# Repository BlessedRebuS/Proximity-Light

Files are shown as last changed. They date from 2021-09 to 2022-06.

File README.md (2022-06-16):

# Proximity-Light
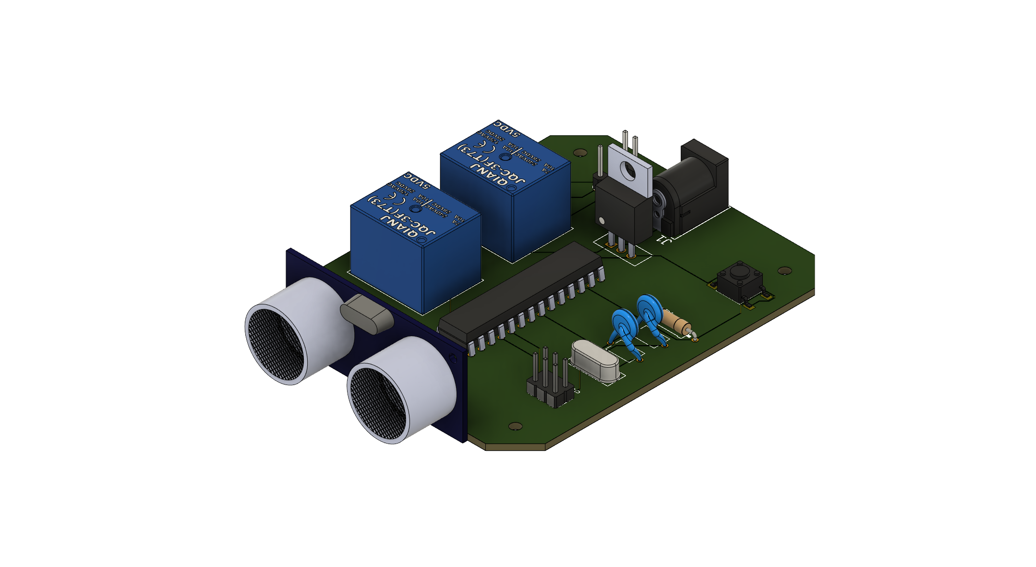
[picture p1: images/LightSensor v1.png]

Sensor Light powered by a ultrasound module (HC-SR04) built on a chip. (SMD version). 
When the proximity sensor sees an obsacle (for example your hand) the relays are toggled **(ON-OFF)** / **(OFF-OF)** and the 12v powers the pins.
The button triggers an interrupt (ATMega328P comes with D2 and D3 digital pin that can be used as interrupts, in this project only the D3 is used) that cycles 3 states:

* Relay 1 ON Relay 2 OFF
* Relay 1 ON Relay 2 ON
* Relay 1 OFF Relay 2 OFF

The project idea is to put two led strips in the pair of pins near the supply that can help you illuminate the kitchen/bathroom/other rooms. Leds can be replaced with all type of stuff you want but it hasn't to drain much current (Max around 0.1 amp), you have only to solder your device in place. Now are only supported devices without data pins, so you have to use only the **VCC** and **GND**.

[See polarity and button](https://github.com/BlessedRebuS/Proximity-Light/blob/main/images/PinButton.png)

# Board

## Electronic Board
Created with Autodesk EAGLE and Fusion360 Electronic.

To connect all pins we simply used autorouting.

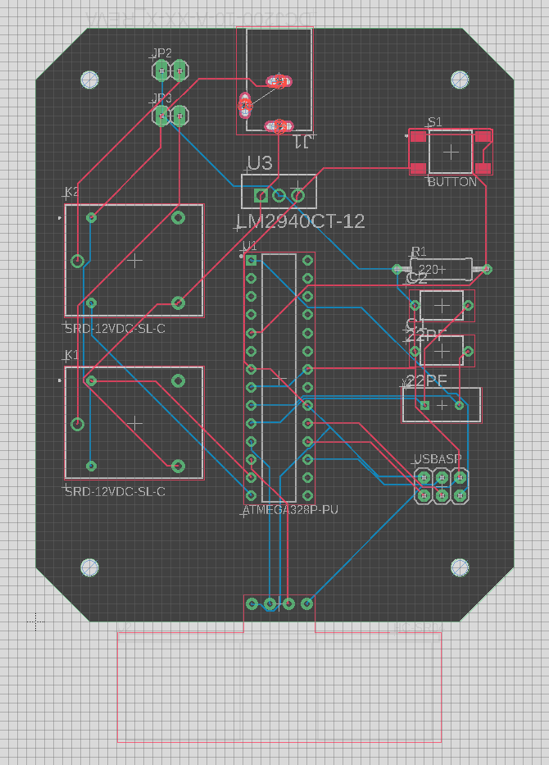
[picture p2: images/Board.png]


## Board Schematic - Libraries
You can find all the libraries *(Footprint, Symbols and 3DModels)* [Here](https://github.com/BlessedRebuS/Proximity-Light/tree/main/libraries/Footprints)

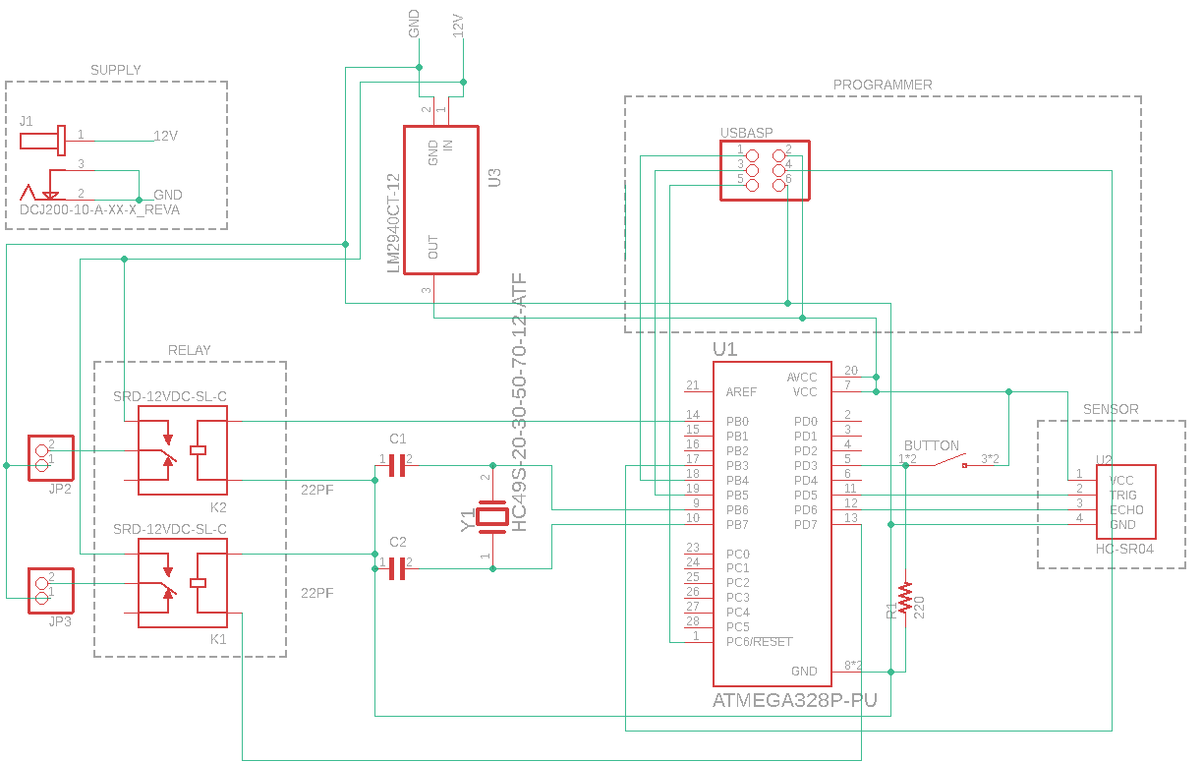
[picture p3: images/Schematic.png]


## 3D Model

Designed and rendered in Fusion360



3D Model STL
# Components

* ATMega328P  [Read more](#about-the-atmega328p)
* 22 PF Capacitors (Not polarized) 2x
* 20 MHZ Quartz Oscillator
* 220-1k OHM Resistor
* Ultrasonic Sensor (HC-SR04)
* 12 to 5V DC Mosfet
* 12V Supply Holder
* 12v Relays x2
* Button
* 2x1 pins x2
* 2x3 pins

# About the ATMega328P

ATMega328p is a very versatile processor, mounted on Arduino, that can be used also separately with a different pinout. In this case the base clock 8MHZ is replaced with the 16MHZ clock (not necessary) connected to the two grounded capacitors to generate the oscillation.

**How to program it?** I suggest to use the [USBASP programmer](www.learningaboutelectronics.com/Articles/Program-AVR-chip-using-a-USBASP-with-10-pin-cable.php) (6 or 10 PIN), but you can use an Arduino using "Arduino as ISP" programming.

## The clock
As [Here](https://doc.riot-os.org/group__boards__atmega328p.html) is explained:

> The ATmega328p has two internal oscillators clocked at 8MHz and at 128kHz that allow it to be operated without any external clock source or crystal. By default the fuses are configured to use the internal 8MHz oscillator and a clock divider resulting in a clock speed of 1MHz. By clearing the CKDIV8 fuse the clock divider can be disabled to operate the ATmega328p at 8MHz without an external clock source. This can be done like this:
> 
> `avrdude -c usbtiny -p m328p -B 32 -U lfuse:w:0xe2:m`
> 
> (Replace usbtiny with the ISP programmer you are using. The -B 32 might be needed on some ISP programmers to communicate with slow ATmega MCUs. It will not be needed anymore after the clock device has been disabled.)
This "board" is configured to use 8MHz as core clock, so that the ATmega328p runs at the highest frequency possible without external clock sources.
By setting the environment variable ATMEGA328P_CLOCK to a custom frequency in Hz (e.g. 1000000 for 1MHz), this core clock can be changed easily. Refer to the datasheet on how to configure the ATmega328p to use an external crystal, an external clock source or the clock divider.
<p align="right">


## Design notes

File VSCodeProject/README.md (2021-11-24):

# Visual Studio Code project

## Required:
* PlatformIO extension

Once you have installed PlatformIO extension you can open the project and re-compile your code.

>You can also switch Board if you desire, you just have to add your configuration to the `platformio.ini` file.
>You can find the configuration for your board [Here](https://docs.platformio.org/en/latest/boards/index.html)

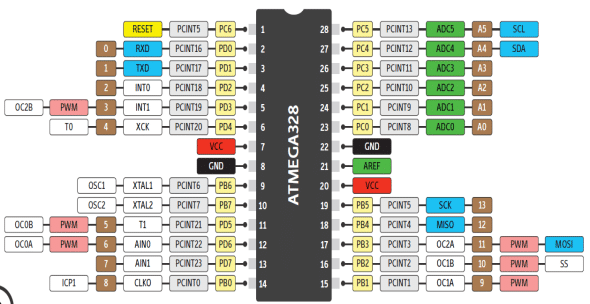
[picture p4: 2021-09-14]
Light-Sensor/img/Full pinout atmega328p.png

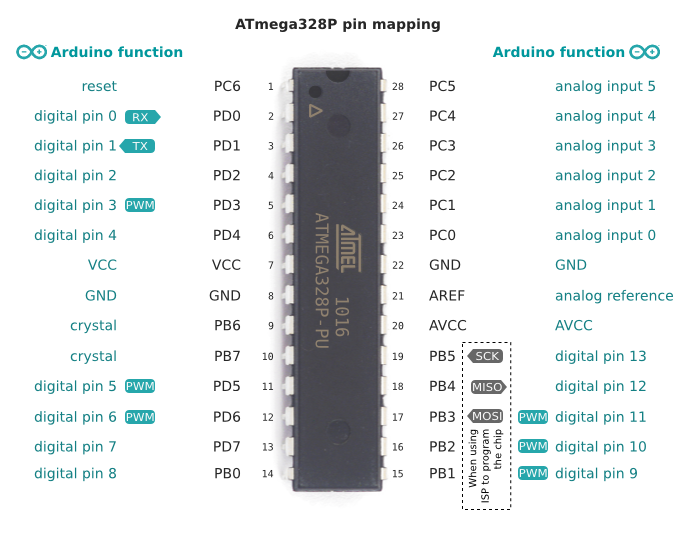
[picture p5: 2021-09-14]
Light-Sensor/img/Pinout atmega328p.png

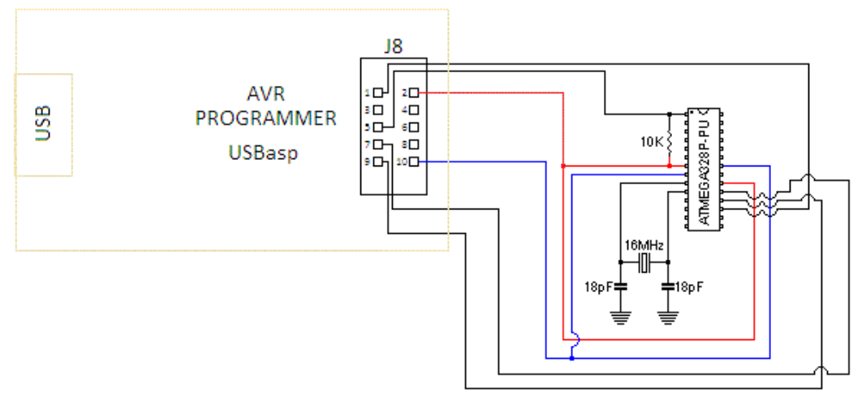
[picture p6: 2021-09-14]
Light-Sensor/img/Immagine 2021-08-31 100949.png

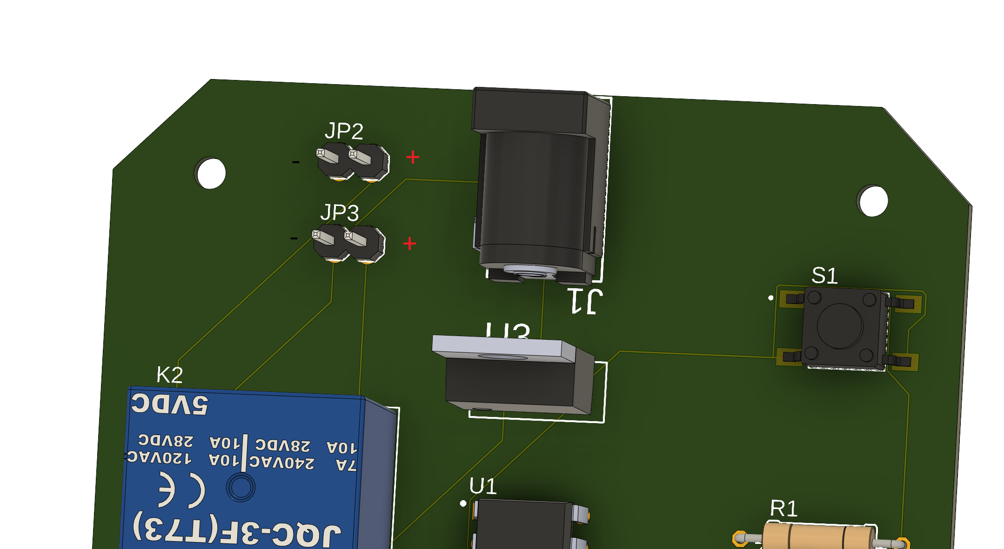
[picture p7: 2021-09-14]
images/PinButton.png

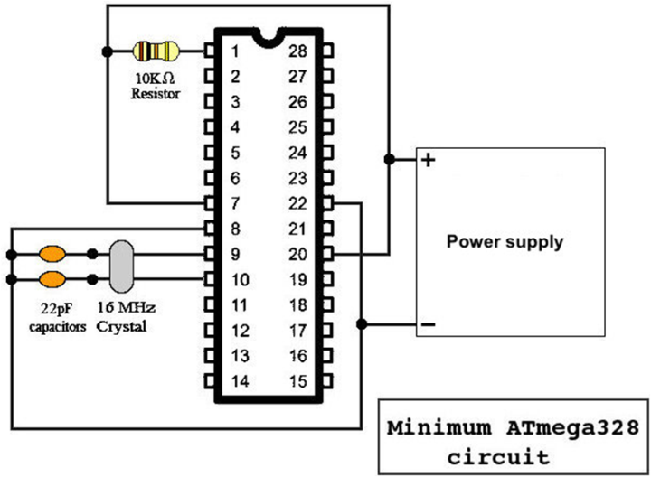
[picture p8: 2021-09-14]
Light-Sensor/img/Clock boost atmega328p.png

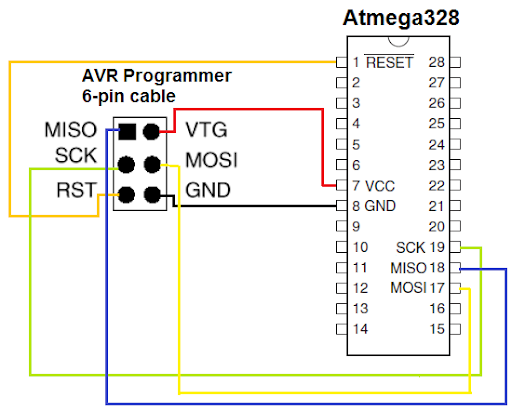
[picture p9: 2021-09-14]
Light-Sensor/img/Usbasp 6 pin atmega328p.png

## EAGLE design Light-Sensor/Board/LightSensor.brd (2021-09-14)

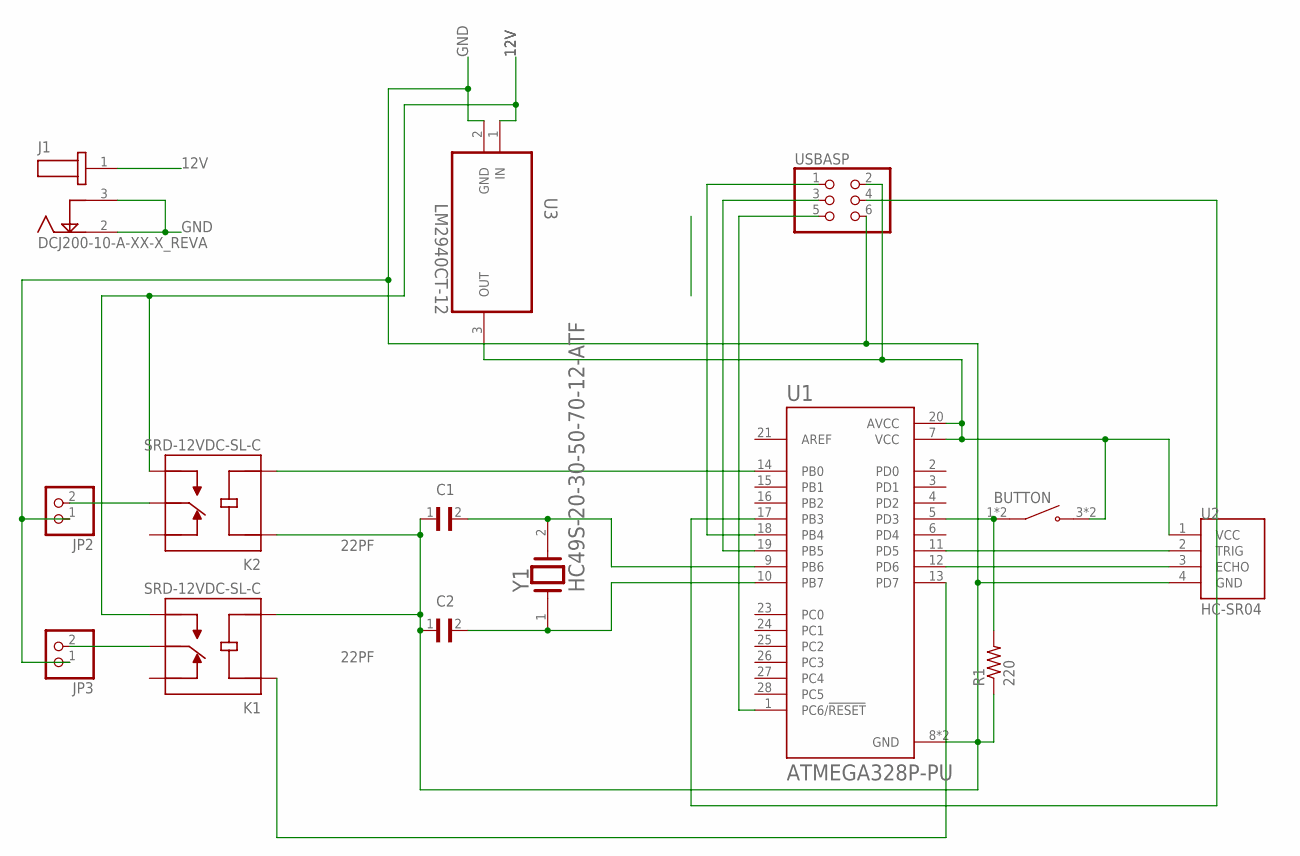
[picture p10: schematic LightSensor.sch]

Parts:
C1, C2: 22PF; CAP_DE21XSA220KN3AX02F
J1: DCJ200-10-A-XX-X_REVA; GCT_DCJ200-10-A-XX-X_REVA
JP2, JP3: PINHD-1X2; 1X02
K1, K2: SRD-12VDC-SL-C; RELAY_SRD-12VDC-SL-C
R1: 220; 0309/12
S1: BUTTON
U1: ATMEGA328P-PU; DIP794W46P254L2967H457Q28B
U2: HC-SR04; XCVR_HC-SR04
U3: LM2940CT-12; TO254P470X1016X2222-3P
USBASP: PINHD-2X3; 2X03
Y1: 20MHZ; MULTICOMP_HC49S-20-30-50-70-12-ATF_0

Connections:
12V: J1.1, K1.NO, K2.NO, U3.1 (IN)
BUTTON: R1.2, S1.1 (COM), S1.2 (COM), U1.5 (PD3)
GND: C1.1, C2.1, J1.2, J1.3, JP2.1, JP3.1, K1.COIL2, K2.COIL1, R1.1, U1.8 (GND), U1.22 (GND), U2.4 (GND), U3.2 (GND), USBASP.6
unnamed: U1.17 (PB3), USBASP.4
unnamed: U1.1 (PC6/!RESET), USBASP.5
unnamed: U1.19 (PB5), USBASP.3
unnamed: U1.18 (PB4), USBASP.1
unnamed: C1.2, U1.9 (PB6), Y1.2
unnamed: C2.2, U1.10 (PB7), Y1.1
unnamed: U1.11 (PD5), U2.2 (TRIG)
unnamed: U1.12 (PD6), U2.3 (ECHO)
unnamed: K1.COIL1, U1.13 (PD7)
unnamed: K2.COIL2, U1.14 (PB0)
unnamed: JP2.2, K2.COM
unnamed: JP3.2, K1.COM
unnamed: S1.3 (NO), S1.4 (NO), U1.7 (VCC), U1.20 (AVCC), U2.1 (VCC), U3.3 (OUT), USBASP.2

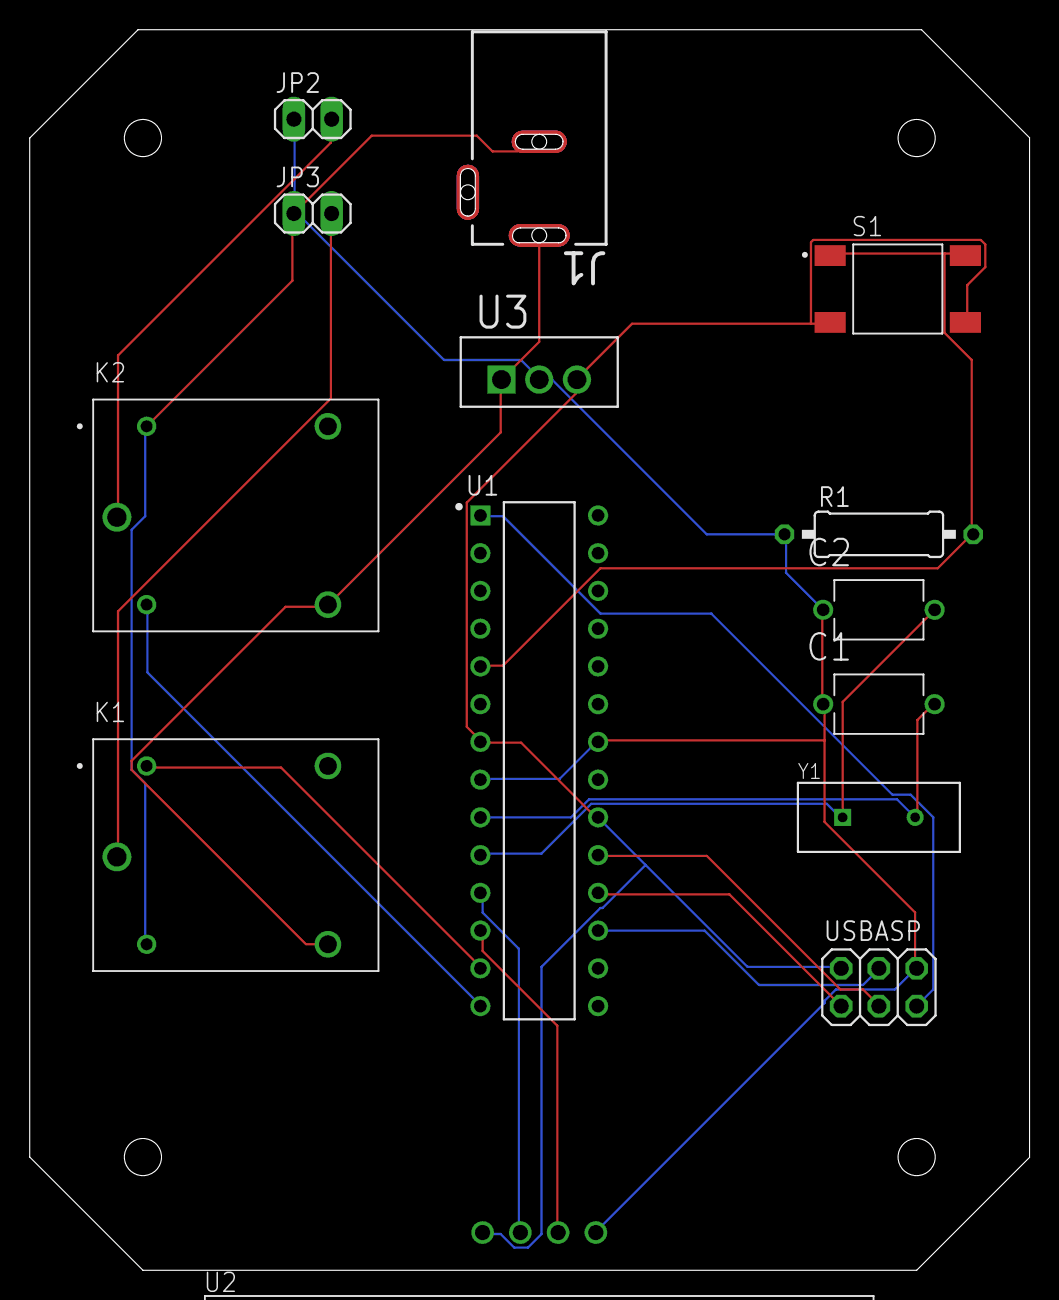
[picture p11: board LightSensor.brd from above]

Board: 2 copper layers, 67.3 x 83.5 mm, 14 parts (0 on the bottom side), 16 nets.

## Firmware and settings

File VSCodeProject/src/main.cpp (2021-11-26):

#include <Arduino.h>

//--------------------------------------
//-----CONFIGURATION PARAMETERS---------
#define TRIG_DISTANCE 17 // cm
#define SWITCH_DELAY 800 // ms

#define DEBUG_MODE true // If 'true' enables Serial communication for better debugging
//--------------------------------------

//--------------------------------------
//--------LIGHTS CONFIGURATION----------
#include <FastLED.h>
#define LIGHTS_ON false // Enables lights, set to true or false

#define DATA_PIN 4
//#define CLK_PIN   4
#define LED_TYPE WS2812B
#define COLOR_ORDER GRB
#define NUM_LEDS 64
CRGB leds[NUM_LEDS];
uint8_t gHue;
#define FRAMES_PER_SECOND 60
#define BRIGHTNESS 80

void rainbow()
{
  gHue++;
  fill_rainbow(leds, NUM_LEDS, gHue, 7);
  FastLED.show();

  FastLED.delay(1000 / FRAMES_PER_SECOND);
}
//--------------------------------------

//--------------------------------------
//-----ARDUINO PIN----------------------
const int trigPin = 5; //default D5
const int echoPin = 6; //default D6

const int buttonPin = 3; //default D3
const int relayPin1 = 7; //default D7
const int relayPin2 = 8; //default D8
//--------------------------------------

//--------------------------------------
//------------FUNCTIONS-----------------
bool status;
int distance;

byte mode = 0;
void switchStatus1(bool value)
{
  if (value)
    digitalWrite(relayPin1, HIGH);
  else digitalWrite(relayPin1, LOW);
}

void switchStatus2(bool value)
{
  if (value)
    digitalWrite(relayPin2, HIGH);
  else digitalWrite(relayPin2, LOW);
}

int getDistance()
{
  // Clears the trigPin condition
  digitalWrite(trigPin, LOW);
  delayMicroseconds(2);
  // Sets the trigPin HIGH (ACTIVE) for 10 microseconds
  digitalWrite(trigPin, HIGH);
  delayMicroseconds(10);
  digitalWrite(trigPin, LOW);
  // Reads the echoPin, returns the sound wave travel time in microseconds
  unsigned long duration = pulseIn(echoPin, HIGH);
  // Calculating the distance
  int distance = duration * 0.034 / 2; // Speed of sound wave divided by 2 (go and back)

  if (DEBUG_MODE)
  {
    Serial.print("Distance: ");
    Serial.print(distance);
    Serial.println(" cm");
  }

  return distance;
}

bool checkDistance(int distance)
{
  if (distance <= TRIG_DISTANCE)
    return true;
  return false;
}

void switchMode()
{
  mode = ++mode % 3;

  if (DEBUG_MODE)
  {
    Serial.print("Mode: ");
    Serial.println(mode);
  }
}

void checkMode()
{
  switch (mode)
  {
  case 0:
    switchStatus1(true);
    switchStatus2(true);
    break;
  case 1:
    switchStatus1(true);
    switchStatus2(false);
    break;
  case 2:
    switchStatus1(false);
    switchStatus2(true);
    break;
  }

  delay(5);
}

void turnOff()
{
  digitalWrite(relayPin1,LOW);
  digitalWrite(relayPin2,LOW);
}

void setup()
{

  pinMode(relayPin1, OUTPUT);
  pinMode(relayPin2, OUTPUT);
  pinMode(echoPin, INPUT);
  pinMode(trigPin, OUTPUT);

  pinMode(buttonPin, INPUT_PULLUP);

  attachInterrupt(digitalPinToInterrupt(buttonPin), switchMode, RISING);

  // Lights setup
  if (LIGHTS_ON)
  {
    FastLED.addLeds<LED_TYPE, DATA_PIN, COLOR_ORDER>(leds, NUM_LEDS).setCorrection(TypicalLEDStrip);
    FastLED.setBrightness(BRIGHTNESS);
    gHue = 0;
  }

  if (DEBUG_MODE)
    Serial.begin(9600);

  mode = 0;
  status = false;
  turnOff();
}

void loop()
{
  distance = getDistance();

  if (checkDistance(distance))
  {
    if (status)
    {
      turnOff();
      status = false;
    }
    else
    {
      checkMode();
      status = true;
    }
    delay(SWITCH_DELAY);
  }

  if (status)
    checkMode();

  if (LIGHTS_ON)
    rainbow();
}
